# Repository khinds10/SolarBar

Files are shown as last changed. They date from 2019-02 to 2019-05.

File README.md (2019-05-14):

# Sunrise Alarm Clock
Schedule your own personal sunrise, improves morning wakefulness

Latest random invention, schedule your own sunrise!

During the day, the blue light in sunlight boosts our attention, memory, energy levels, reaction times, and overall mood.
Blue light suppresses the release of melatonin, for morning use only :)

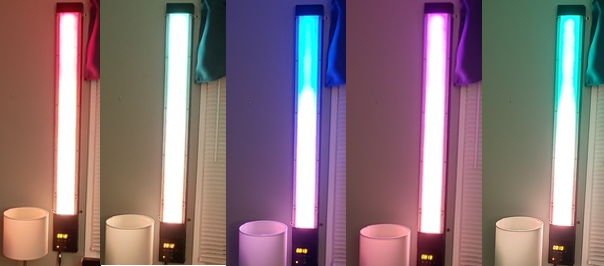
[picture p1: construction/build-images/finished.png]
Finished


Sunrise Alarm Clock (https://www.youtube.com/watch?v=JoXHWPglelI)

#### Flashing RaspberriPi Hard Disk / Install Required Software (Using Ubuntu Linux)

Download "RASPBIAN JESSIE LITE"
https://www.raspberrypi.org/downloads/raspbian/

**Create your new hard disk for DashboardPI**
>Insert the microSD to your computer via USB adapter and create the disk image using the `dd` command
>
> Locate your inserted microSD card via the `df -h` command, unmount it and create the disk image with the disk copy `dd` command
>
> $ `df -h`
> */dev/sdb1       7.4G   32K  7.4G   1% /media/XXX/1234-5678*
> a
> $ `umount /dev/sdb1`
>
> **Caution: be sure the command is completely accurate, you can damage other disks with this command**
>
> *if=location of RASPBIAN JESSIE LITE image file*
> *of=location of your microSD card*
>
> $ `sudo dd bs=4M if=/path/to/raspbian-jessie-lite.img of=/dev/sdb`
> *(note: in this case, it's /dev/sdb, /dev/sdb1 was an existing factory partition on the microSD)*

**Setting up your RaspberriPi**

*Insert your new microSD card to the raspberrypi and power it on with a monitor connected to the HDMI port*

Login
> user: **pi**
> pass: **raspberry**

Change your account password for security
>`sudo passwd pi`

Enable RaspberriPi Advanced Options
>`sudo raspi-config`

Choose:
`1 Expand File System`

`9 Advanced Options`
>`A2 Hostname`
>*change it to "SOLARLAMP"*
>
>`A4 SSH`
>*Enable SSH Server*
>
>`A7 I2C`
>*Enable i2c interface*
>
>`P4 SPI`
>*Enable/Disable automatic loading of SPI kernel module*
>

**Enable the English/US Keyboard**

>`sudo nano /etc/default/keyboard`

> Change the following line:
>`XKBLAYOUT="us"`

**Reboot PI for Keyboard layout changes / file system resizing to take effect**
>$ `sudo shutdown -r now`

**Auto-Connect to your WiFi**

>`sudo nano /etc/wpa_supplicant/wpa_supplicant.conf`

Add the following lines to have your raspberrypi automatically connect to your home WiFi
*(if your wireless network is named "linksys" for example, in the following example)*

	network={
	   ssid="linksys"
	   psk="WIRELESS PASSWORD HERE"
	}

**Reboot PI to connect to WiFi network**

>$ `sudo shutdown -r now`
>
>Now that your PI is finally on the local network, you can login remotely to it via SSH.
>But first you need to get the IP address it currently has.
>
>$ `ifconfig`
>*Look for "inet addr: 192.168.XXX.XXX" in the following command's output for your PI's IP Address*

**Go to another machine and login to your raspberrypi via ssh**

> $ `ssh pi@192.168.XXX.XXX`

**Start Installing required packages**

>$ `sudo apt-get update`
>
>$ `sudo apt-get upgrade`
>
>$ `sudo apt-get install memcached vim git python-gpiozero python-smbus i2c-tools python-imaging python-smbus build-essential python-dev rpi.gpio python3 python3-pip python-memcache python3-spidev python-spidev`

**Update local timezone settings

>$ `sudo dpkg-reconfigure tzdata`

`select your timezone using the interface`

**Setup the simple directory `l` command [optional]**

>`vi ~/.bashrc`
>
>*add the following line:*
>
>`alias l='ls -lh'`
>
>`source ~/.bashrc`

**Fix VIM default syntax highlighting [optional]**

>`sudo vi  /etc/vim/vimrc`
>
>uncomment the following line:
>
>_syntax on_

**Install i2c Python Drivers**

Install the NeoPixel Driver as follows 

>`sudo apt-get install build-essential python-dev git scons swig`
>
>`sudo pip3 install --upgrade setuptools`
>
>`sudo pip3 install rpi_ws281x`
>
>`cd rpi_ws281x`
>
>`scons`
>
>`cd python`
>
>`sudo python setup.py install`
>
>`cd examples/`
>
>`sudo python strandtest.py`

# Supplies Needed

**5V Power Supply**

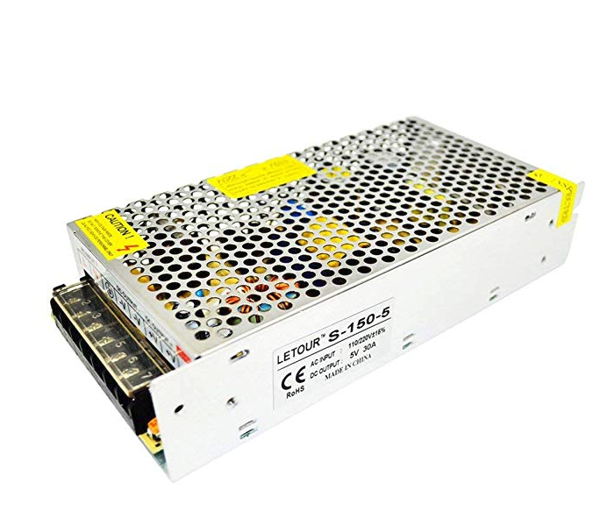
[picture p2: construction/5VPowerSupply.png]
5V Power Supply


**I2C 7 SEGMENT**

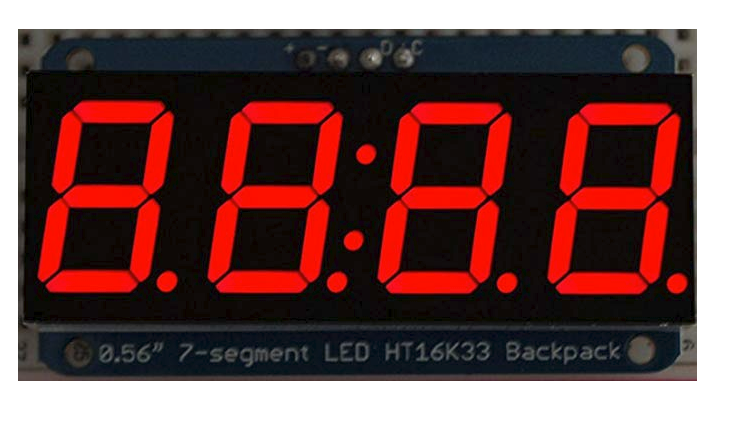
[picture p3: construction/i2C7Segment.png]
I2C 7 SEGMENT


**Microchip MCP3008**

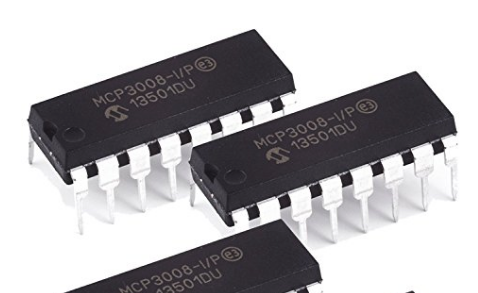
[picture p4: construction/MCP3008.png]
Microchip MCP3008


**Momentary Tactile Tact Push Button Switch [x5]**

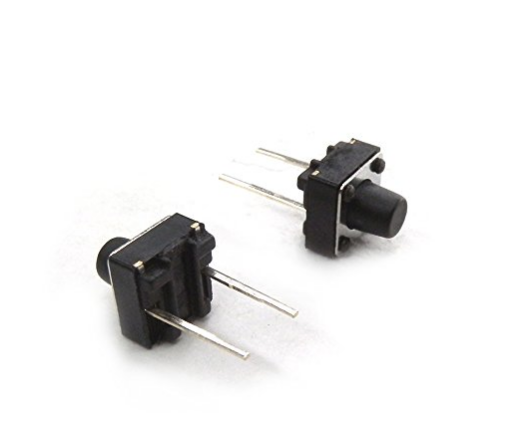
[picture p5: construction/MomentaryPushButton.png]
Momentary Tactile Tact Push Button Switch


**PI ZERO W**

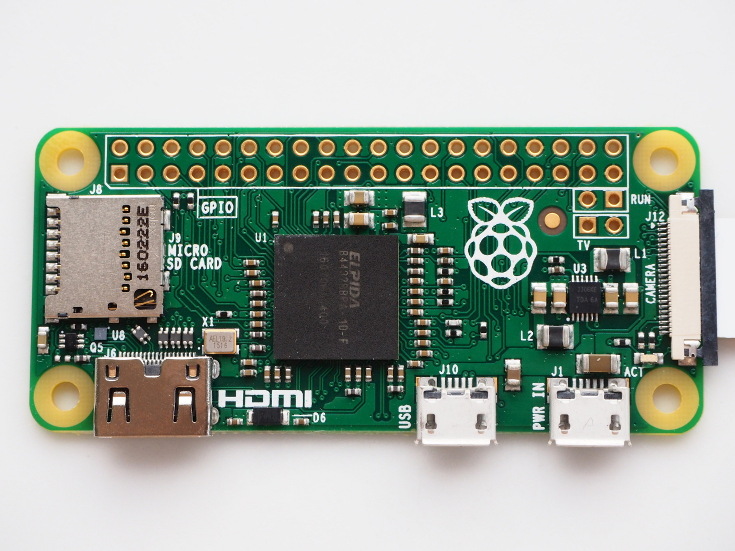
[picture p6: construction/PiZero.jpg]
PI ZERO W


**Logarithmic Slide Potentiometer**

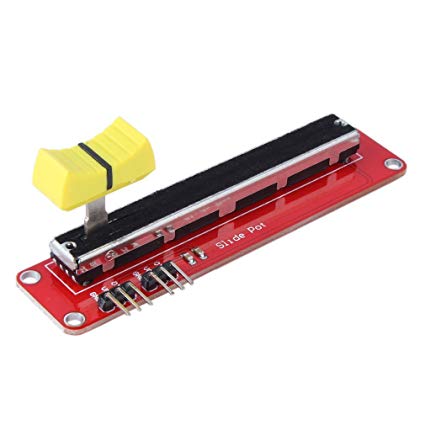
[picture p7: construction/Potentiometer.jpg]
Logarithmic Slide Potentiometer


**WS2812B Individually Addressable RGB LED Strip [x4]**

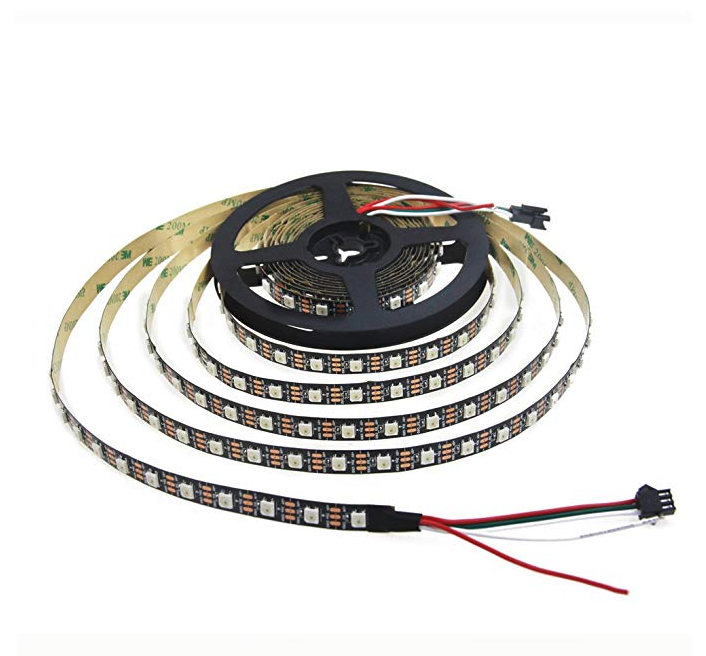
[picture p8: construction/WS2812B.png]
WS2812B Individually Addressable RGB LED Strip


**Thin Plexi Glass Sheet**

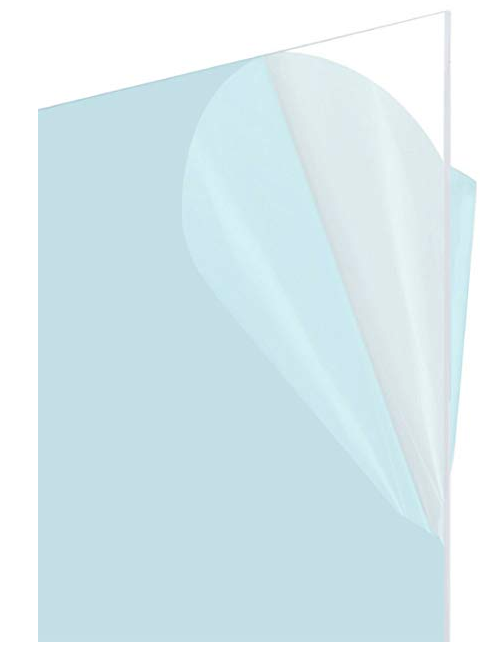
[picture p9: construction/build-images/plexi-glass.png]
Plexi Glass


**Frosted Spray Paint**

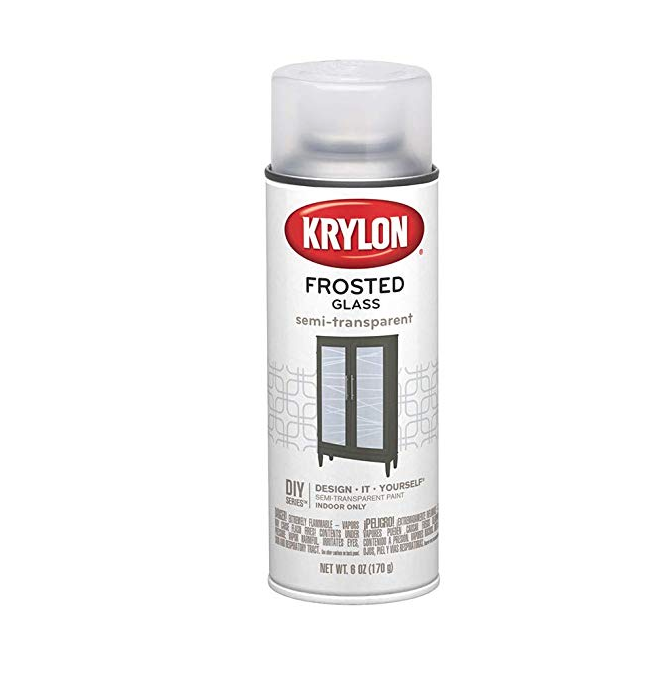
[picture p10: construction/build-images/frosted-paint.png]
Frosted Spray Paint


### 3D Print the Controller Panel

Using the .x3g files included in the "3D Print/" folder print the main control panel cover, which will house the slider, buttons, LED and 7 Segment display

### Building the Lamp

**Build Wood Frame**

I've built a wooden frame for the LED strips to be enclosed in and painted it black.

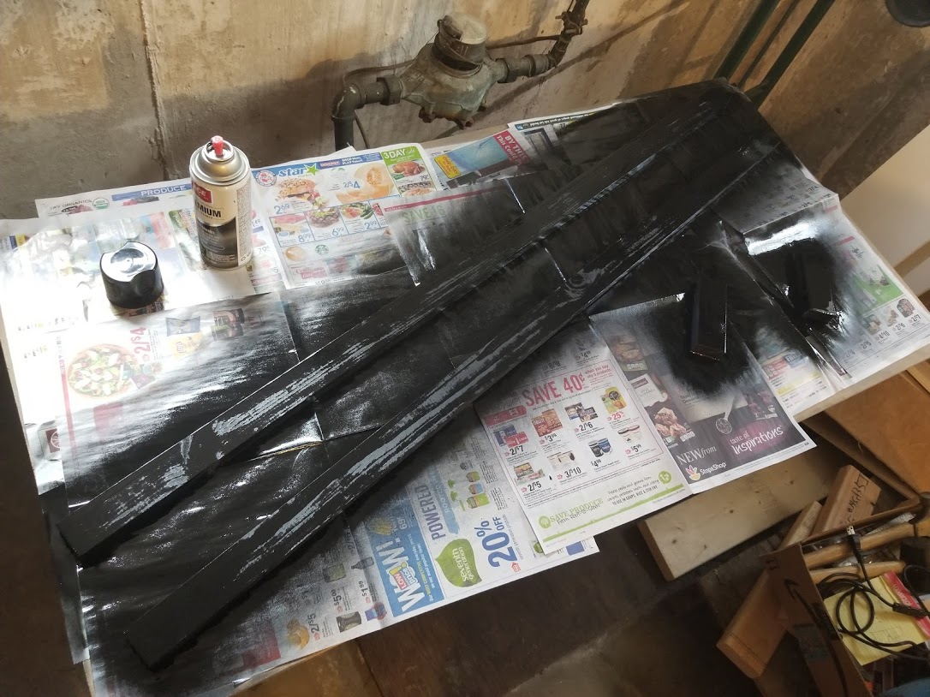
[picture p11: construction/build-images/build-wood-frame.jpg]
Build Wood Frame


**Paint Plexi Glass**

With some frosted spray paint, paint the glass so that it defuses the light from the strips.

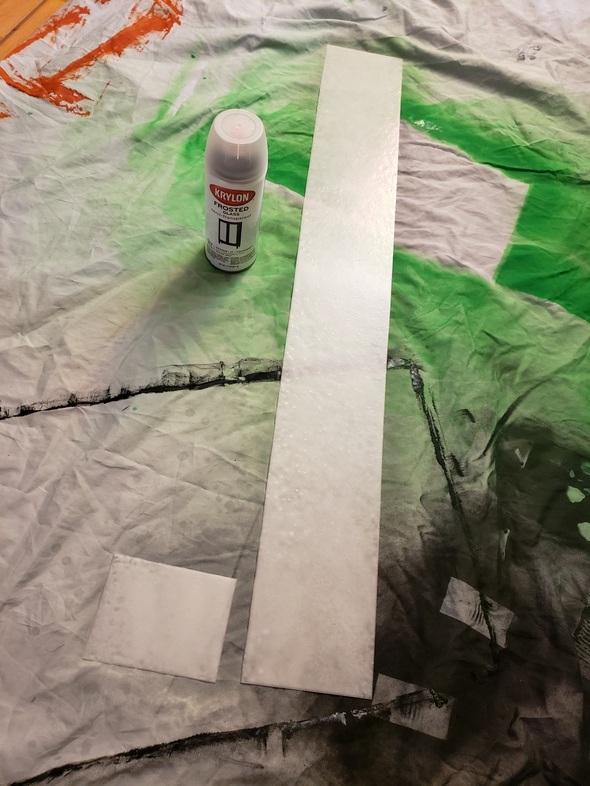
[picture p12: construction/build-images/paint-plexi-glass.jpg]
Paint Plexi Glass


**Mount Strips**

Using simple tape and the stickiness of the backside of the LED strips, mount the 4 strips to the wooden base

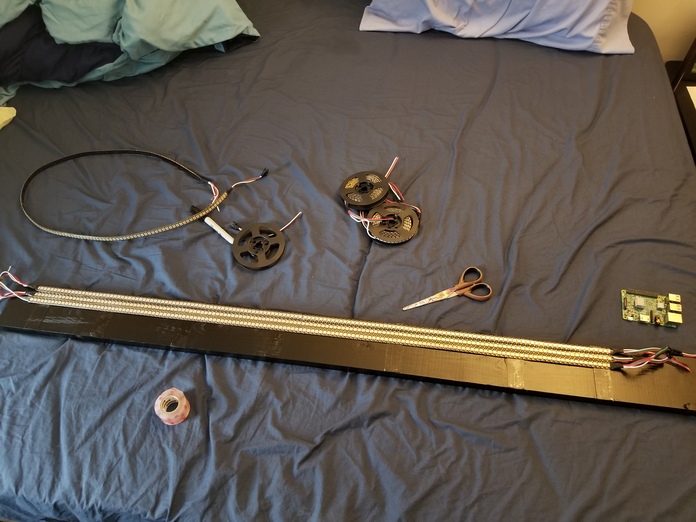
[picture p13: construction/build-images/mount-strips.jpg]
Mount Strips


**Mount Buttons**

Mount the buttons and the yellow LED, I've used hot glue to hold the buttons and LED in place.

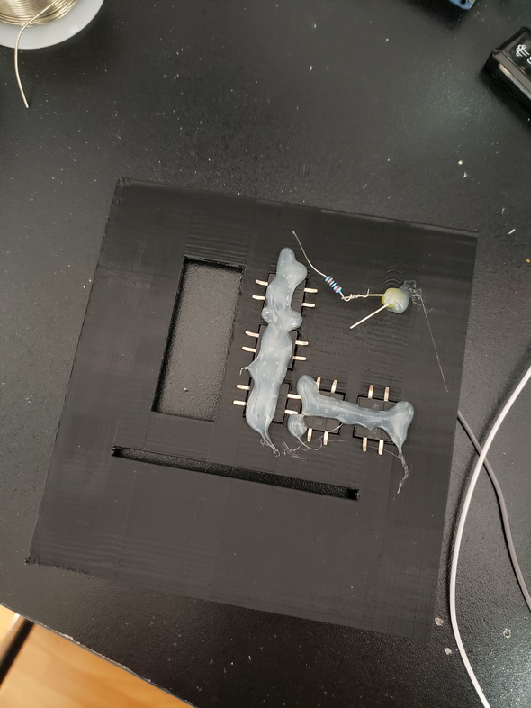
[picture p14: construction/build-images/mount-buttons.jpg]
Mount Buttons


**Mount Buttons on Panel**

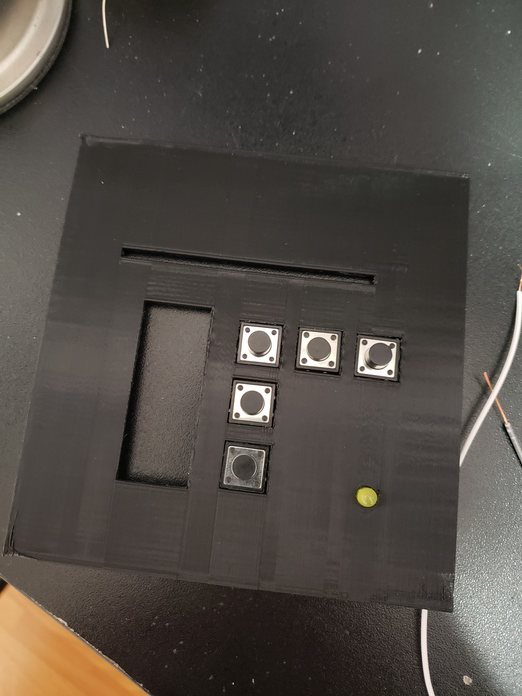
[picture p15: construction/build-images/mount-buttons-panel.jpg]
Mount Buttons on Panel


**Mount Chip on the Slider**

Following the provided schematic, solder the chip wiring in place and connect to the logarithmic slider, glue the chip with solder connections to the back of the slider.

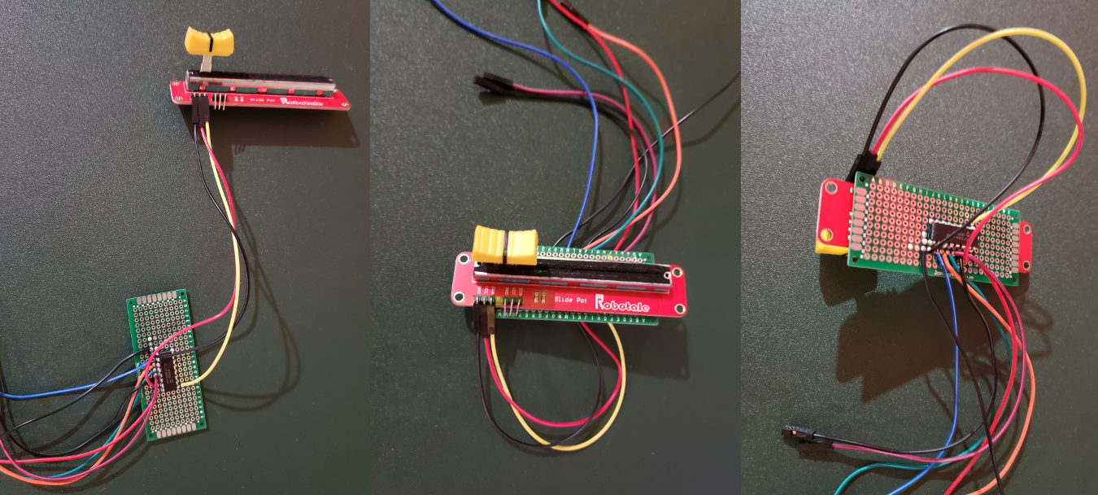
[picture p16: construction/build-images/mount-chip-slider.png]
Mount Chip on the slider


### Wiring the Components

Use the following Schematic to connect all the components to have the lamp work properly.

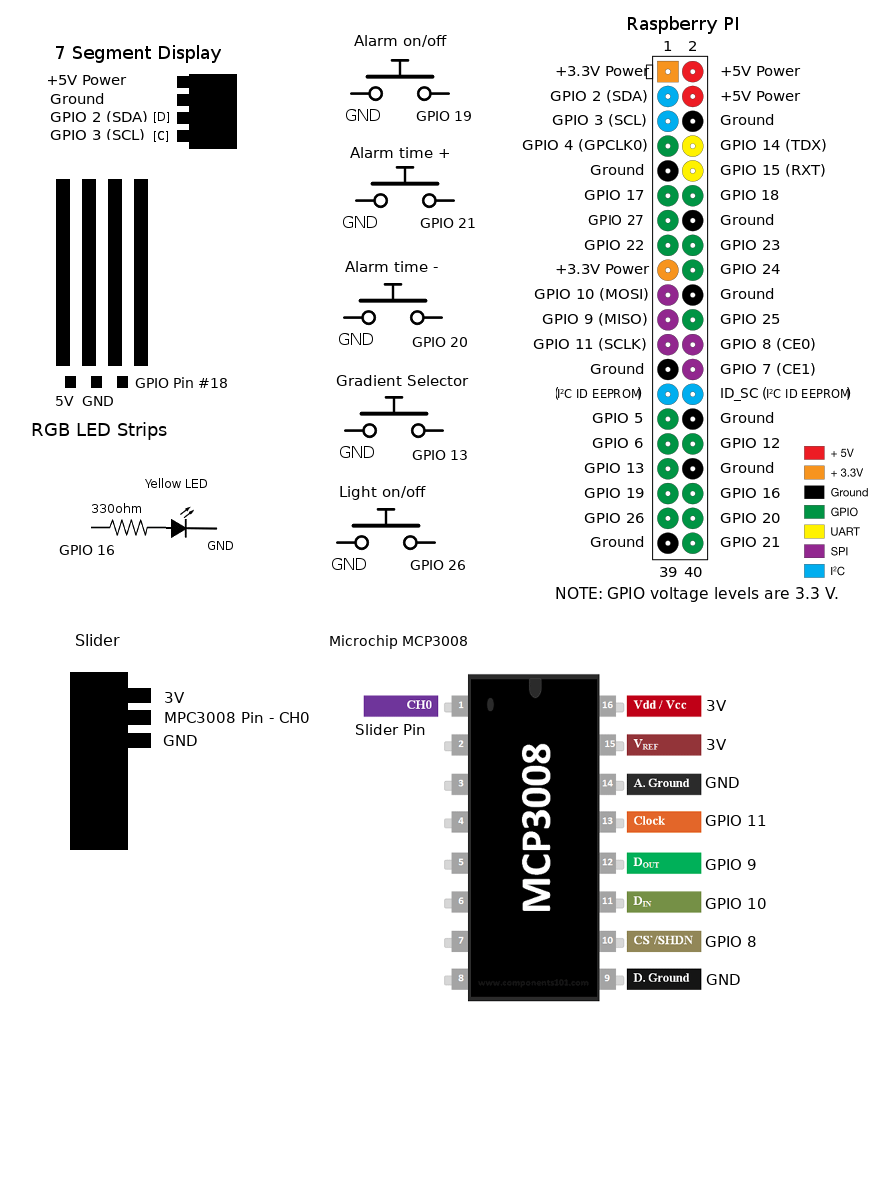
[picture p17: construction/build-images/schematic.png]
Schematic


**Wire Panel**

Connect all wiring to the components glued on the panel to connect to the raspberrypi.

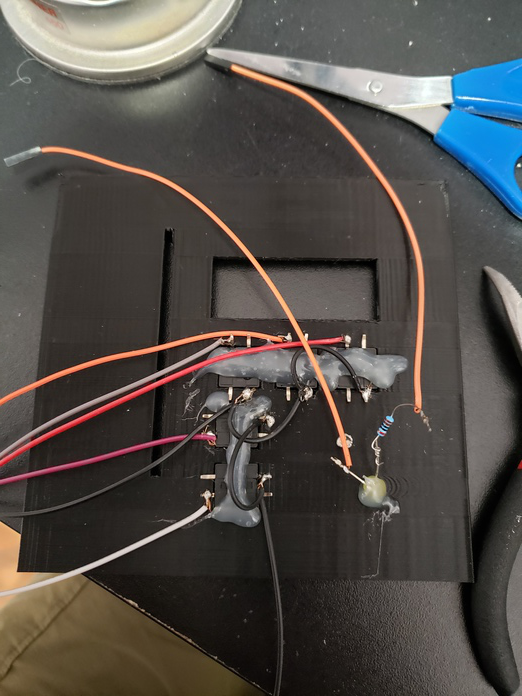
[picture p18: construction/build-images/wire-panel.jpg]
Wire Panel


**Wire Pi**

Finally attach the PiZero to the back board of the LED wooden case with tape or glue and then connect the wiring according the provided schematic.

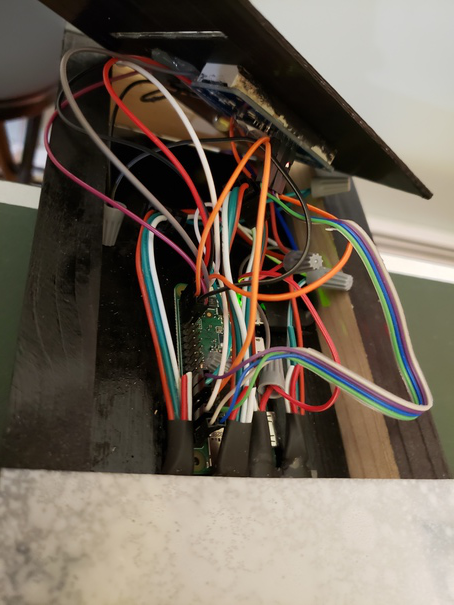
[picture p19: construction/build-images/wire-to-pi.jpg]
Wire Pi


**Mount Panel**

Fasten the control panel on the bottom of the LED case.

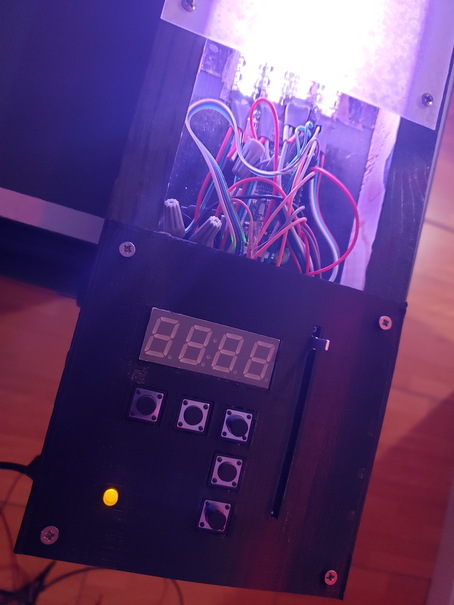
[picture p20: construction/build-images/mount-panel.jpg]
Mount Panel


**Apply Plexi Glass**

Attach cut and painted plexi glass to the LED case with screws

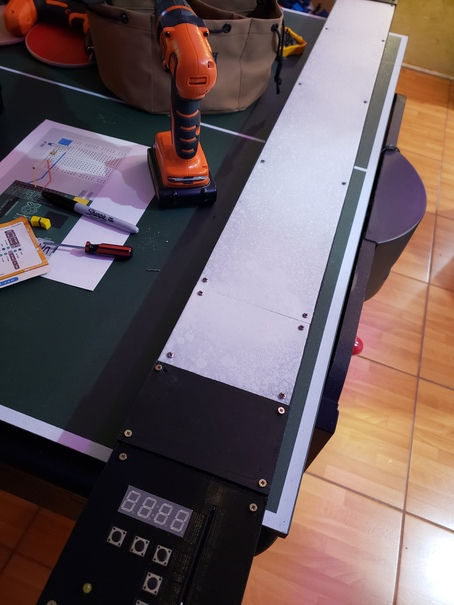
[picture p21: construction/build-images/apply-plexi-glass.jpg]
Apply Plexi Glass


**Mount on the Wall**

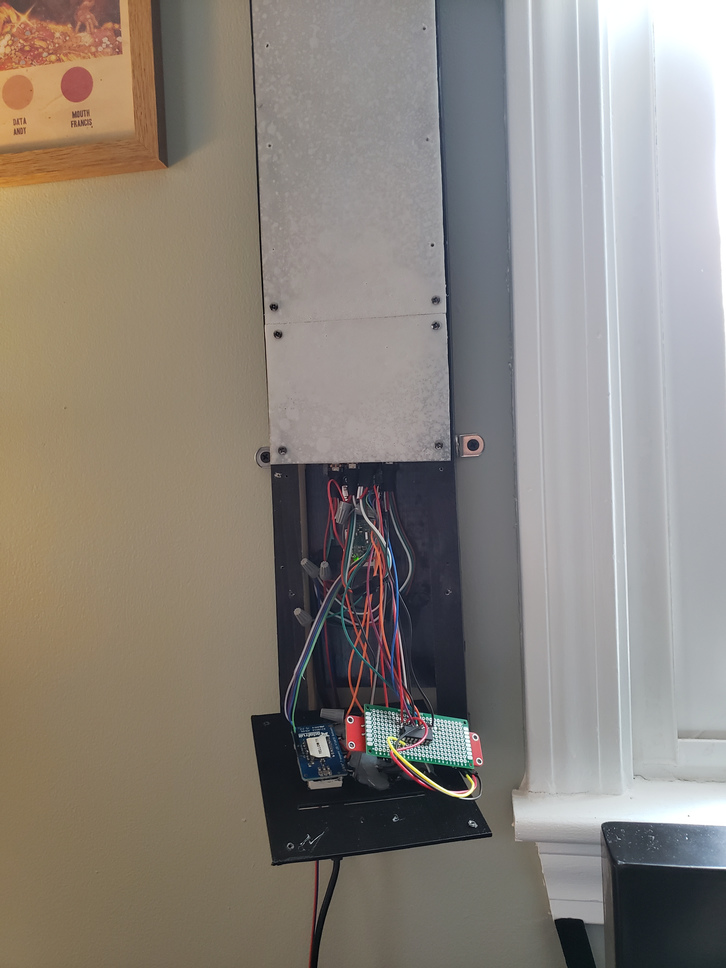
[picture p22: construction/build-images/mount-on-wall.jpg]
Mount on the Wall


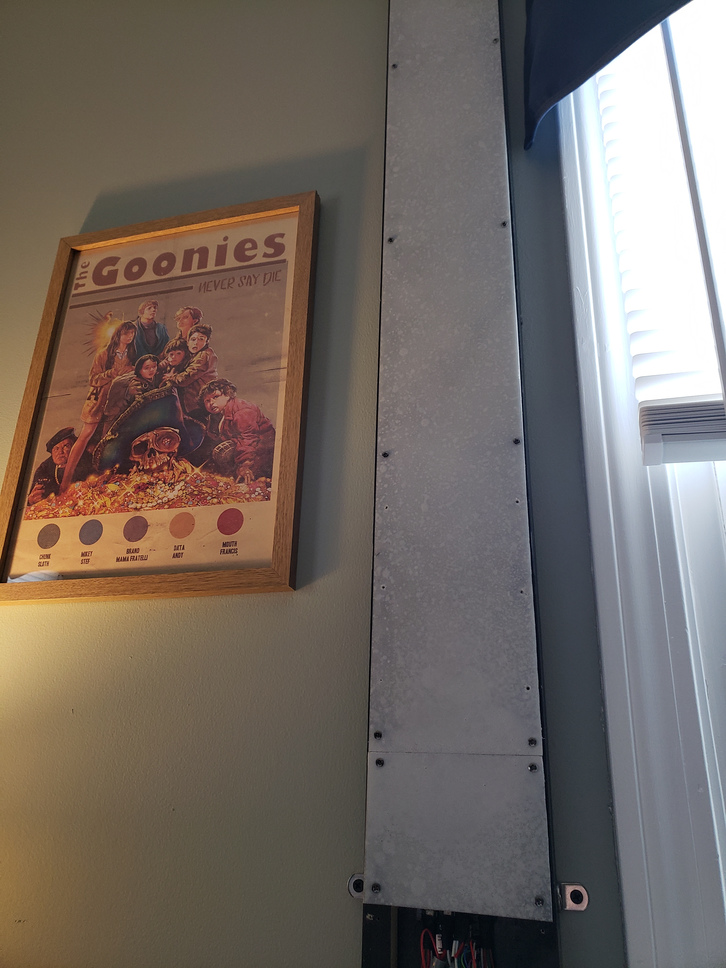
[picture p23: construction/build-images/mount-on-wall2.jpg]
Mount on the Wall


### Set pi user crontab 

Enter the following line for a minute by minute crontab

`$ crontab -e`

`0 3 * * * python /home/pi/SolarBar/Alarm.py > /dev/null 2>&1`

`@reboot python /home/pi/SolarBar/Buttons.py > /dev/null 2>&1`

`@reboot python /home/pi/SolarBar/ControlPanel.py > /dev/null 2>&1`

`@reboot python /home/pi/SolarBar/Slider.py > /dev/null 2>&1`

### Set root user crontab (this library requires root access)

Set "on reboot" to run the candle python script forever

`$ sudo su`

`$ crontab -e`

`@reboot python /home/pi/SolarBar/LEDs.py > /dev/null 2>&1`

# Finished!

Finished

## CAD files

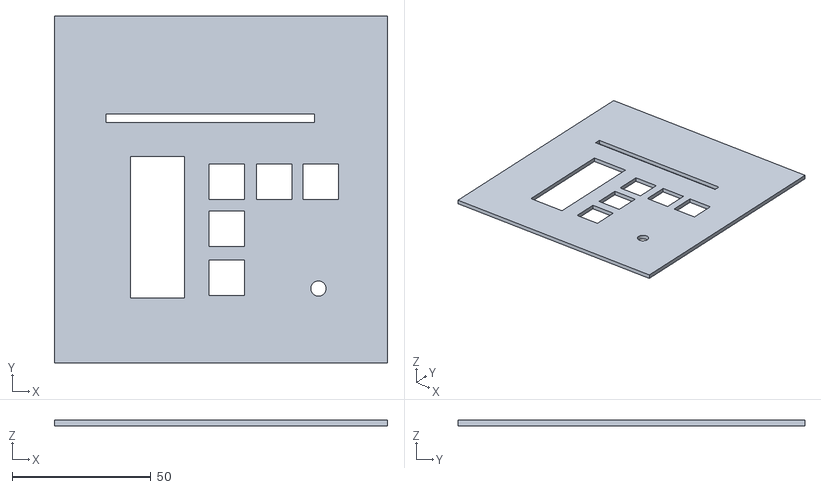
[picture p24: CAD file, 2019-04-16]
3D Print/ControlPanel-final-cut.stl
120.0 x 125.0 x 2.00

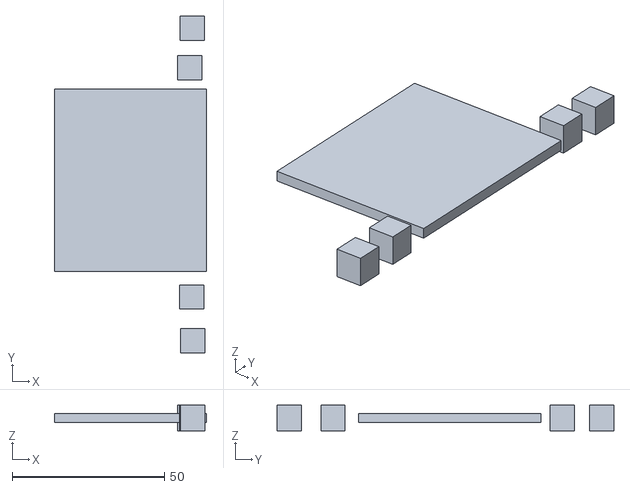
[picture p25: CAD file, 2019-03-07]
3D Print/ButtonMount.stl
50.0 x 110.7 x 8.50

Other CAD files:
3D Print/ControlPanel.stl
3D Print/ControlPanel-Cut-Large-Buttons.blend
3D Print/ControlPanel-Cut.blend
3D Print/ControlPanel-button-mount.blend
3D Print/ControlPanel-final-cut.blend
3D Print/ControlPanel-pre-cut.blend
3D Print/ControlPanel.blend

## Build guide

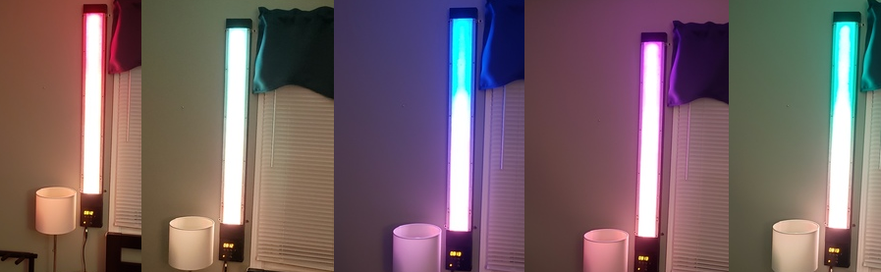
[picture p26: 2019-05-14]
construction/build-images/gradients.png

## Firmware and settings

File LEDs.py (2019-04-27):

#! /usr/bin/python
# Solar Bar, color strip controller
# Kevin Hinds http://www.kevinhinds.com
# License: GPL 2.0
import time, commands, subprocess, re, json, sys, os, memcache, numpy
from PIL import Image
from neopixel import *
import includes.data as data

# LED strip configuration:import settings as settings
LED_COUNT       = 576     # Number of LED pixels.
LED_STRIP_COUNT = 4       # How many strips are there total for the number of pixels
LED_PIN         = 18      # GPIO pin connected to the pixels (18 uses PWM!).
LED_FREQ_HZ     = 800000  # LED signal frequency in hertz (usually 800khz)
LED_DMA         = 10      # DMA channel to use for generating signal (try 10)
LED_BRIGHTNESS  = 255     # Set to 0 for darkest and 255 for brightest
LED_INVERT      = False   # True to invert the signal (when using NPN transistor level shift)
LED_CHANNEL     = 0       # set to '1' for GPIOs 13, 19, 41, 45 or 53
LED_TOTAL_STRIPS = LED_COUNT/LED_STRIP_COUNT

##################################################
######## YOU HAVE TO RUN AS ROOT!
##################################################

# setup the strip
strip = Adafruit_NeoPixel(LED_COUNT, LED_PIN, LED_FREQ_HZ, LED_DMA, LED_INVERT, LED_BRIGHTNESS, LED_CHANNEL, ws.WS2811_STRIP_GRB)
strip.begin()

def reset():
    """turn all lights off RGB = 000"""
    global isIllumniated
    print "reset()"
    for i in range(0, LED_COUNT):
        strip.setPixelColor(i, Color(0, 0, 0))
    isIllumniated = False
    strip.show()

def illuminate():
    """turn on the strip to the current gradient set"""
    global isIllumniated, currentImage
    print "illuminate()"
    currentPixel = 0
    evenNumberedStrip = False
    for currentStrip in range(0, LED_COUNT, (LED_TOTAL_STRIPS)):
        currentPixel = 0
        if evenNumberedStrip:
            for ledLight in range(currentStrip, currentStrip + (LED_TOTAL_STRIPS), 1):
                r,g,b,a = currentImage[currentPixel]
                strip.setPixelColor(ledLight, Color(r,g,b))
                currentPixel = currentPixel + 1
        else:
            for ledLight in range(currentStrip + (LED_TOTAL_STRIPS), currentStrip, -1):
                r,g,b,a = currentImage[currentPixel]
                strip.setPixelColor(ledLight, Color(r,g,b))
                currentPixel = currentPixel + 1

        # the LED strips are upside down, right side up sequentially on the device, so we must iterate through back and forth the LEDs
        evenNumberedStrip = not evenNumberedStrip       
    isIllumniated = True
    strip.show()

def saveDebugImage():
    """save debug image to show what the panel will display"""
    global currentImage
    newImage = Image.new("RGB", (1,len(currentImage)))
    newImage.putdata(currentImage)
    newImage.save('/home/pi/SolarBar/currentPanelColors.png')

def shiftGradient():
    """move the gradient"""
    print "shiftGradient() = " + str(currentSunrisePosition)
    global currentSunrisePosition, currentImage
    if currentSunrisePosition > (imgHeight - 1):
        currentSunrisePosition = imgHeight - 1        
    currentImage = imagePixels[currentSunrisePosition:currentSunrisePosition + (LED_TOTAL_STRIPS)]
    saveDebugImage()
    
def getGradient():
    """get the gradient chosen into memory"""
    global currentImage, imgWidth, imgHeight, imagePixels
    print "getGradient() = " + str(gradientSet)
    im = Image.open('/home/pi/SolarBar/gradients/' + str(gradientSet) + '.png')
    imagePixels = list(im.getdata())
    imgWidth, imgHeight = im.size

    # the sun color is always at the bottom and can 'consume' more and more of the current gradient
    currentSunrisePosition = 0
    sunColor = imagePixels[-1]

    # cut one line out of the image and pad it with the "full sun color" at the bottom
    completeGradient = []
    for i in range(0, (imgWidth * imgHeight) * 2, imgWidth):
        if i < (imgWidth * imgHeight):
            completeGradient.append(imagePixels[i])
        else:
            completeGradient.append(sunColor)
    imagePixels = completeGradient

    # get current gradient as is to be manipulated, original image 
    #   that the completeGradient can slowly take over as the "sun rises" or control panel adjusted
    currentImage = imagePixels[0:(LED_TOTAL_STRIPS)]
    saveDebugImage()

def getCurrentPanelSettings():
    """get the currently set values for what the light panel is supposed to reflect"""
    global gradientSet, lightOn, currentPosition
    gradientSet = data.getJSONFromDataFile('/home/pi/SolarBar/data/gradient.data')
    lightOn = data.getJSONFromDataFile('/home/pi/SolarBar/data/lightOn.data')
    try:
        currentPosition = int(data.getJSONFromDataFile('/home/pi/SolarBar/data/position.data'))
        currentPosition = int(currentPosition * 4.5)
    except:
        currentPosition = 0
    print "getCurrentPanelSettings() = gradientSet: " + str(gradientSet) + " / lightOn: " + str(lightOn) + " / currentPosition: " + str(currentPosition)

# load current settings for the panel
gradientSet, lightOn, currentPosition, isIllumniated = ["1", "0", "0", False]
prevGradient, prevPosition= ["1", "0"]
imgWidth, imgHeight = [0,0]
imagePixels = None
getCurrentPanelSettings()
reset()
getGradient()

# begin the panel
while True:
    try:
        # light on/off if changed
        if lightOn == "1" and not isIllumniated:
            illuminate()
        if lightOn == "0" and isIllumniated:
            reset()

        # update gradient if new one is set
        if gradientSet != prevGradient:
            getGradient()
            if isIllumniated:
                illuminate()
            prevGradient = gradientSet

        # update 
        if currentPosition != prevPosition:
            currentSunrisePosition = currentPosition
            shiftGradient()
            if isIllumniated:
                illuminate()
            prevPosition = currentPosition

        # go around again
        getCurrentPanelSettings()
        time.sleep(0.1)
    except (Exception):
        time.sleep(0.1)

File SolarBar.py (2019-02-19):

#! /usr/bin/python
# Solar Bar, main script
# Kevin Hinds http://www.kevinhinds.com
# License: GPL 2.0
import time, commands, subprocess, re, json, sys, os, memcache
from datetime import datetime
mc = memcache.Client(['127.0.0.1:11211'], debug=0)
from Adafruit_LED_Backpack import SevenSegment
import RPi.GPIO as GPIO

# setup alarm on / off LED
GPIO.setmode(GPIO.BCM)
GPIO.setwarnings(False)
GPIO.setup(16,GPIO.OUT)

# 7 Segment Clock on i2c on address 0x70
segment = SevenSegment.SevenSegment(address=0x71)

# initialize the display, must be called once before using the display.
segment.begin()
segment.set_brightness(3)
segment.set_colon(True)

# application defaults
sunriseTimeHour = 7
sunriseTimeMin = 0
alarmOn = 'False'
lightOn = 'False'

def getJSONFromDataFile(fileName):
    """get JSON contents from file in question"""
    try:
        with open(fileName) as locationFile:    
            return json.load(locationFile)
    except (Exception):
        return ""

def toggleAlarmOnLight(alarmOn):
    """toggle alarm on light"""
    print alarmOn
    if alarmOn == 'True':
        GPIO.output(16,GPIO.HIGH)
    else: 
        GPIO.output(16,GPIO.LOW)

def saveAlarmTime(hour, minute):
    """save the hour and minutes the sunrise alarm is set to"""
    f = file('alarm.data', "w")
    alarmTime = [hour, minute]
    f.write(str(json.dumps(alarmTime)))

def saveAlarmOn(alarmOn):
    """save if the alarm is turned on or off"""
    f = file('alarmSet.data', "w")
    f.write(str(json.dumps(alarmOn)))
    
def saveLightOn(lightOn):
    """save if the light is turned on or off"""
    f = file('lightOn.data', "w")
    f.write(str(json.dumps(lightOn)))
    
def setDisplay(hour, minute):
    """set 7 segment display with hour and minute"""
    if (hour > 12):
        hour = hour - 12  
    segment.clear()
    segment.set_digit(0, int(hour / 10))
    segment.set_digit(1, hour % 10)
    segment.set_digit(2, int(minute / 10))
    segment.set_digit(3, minute % 10)
    segment.write_display()

# run script, check for button presses
alarm = getJSONFromDataFile('alarm.data')
alarmOn = getJSONFromDataFile('alarmSet.data')
toggleAlarmOnLight(alarmOn)
setDisplay(alarm[0], alarm[1])
while True:
    buttonPress = mc.get("BUTTON")
    if buttonPress is not "":
        print buttonPress

    # increase time by 15 min increments, increasing hour up to 23 hundred
    if buttonPress == "UP":
        sunriseTimeMin = sunriseTimeMin + 15
        if sunriseTimeMin > 45:
            sunriseTimeMin = 0
            sunriseTimeHour = sunriseTimeHour + 1
        if sunriseTimeHour > 23:
            sunriseTimeHour = 0

        # show new alarm time on 7 segment
        setDisplay(sunriseTimeHour, sunriseTimeMin)
        saveAlarmTime(sunriseTimeHour, sunriseTimeMin)
        time.sleep(1)

    # decrease time by 15 min increments, resetting hour back to 23 hundred
    if buttonPress == "DOWN":
        sunriseTimeMin = sunriseTimeMin - 15
        if sunriseTimeMin < 0:
            sunriseTimeMin = 45
            sunriseTimeHour = sunriseTimeHour - 1
        if sunriseTimeHour < 0:
            sunriseTimeHour = 23

        # show new alarm time on 7 segment
        setDisplay(sunriseTimeHour, sunriseTimeMin)
        saveAlarmTime(sunriseTimeHour, sunriseTimeMin)
        time.sleep(1)

    # turn on / off the alarm LED, save the settings to file
    elif buttonPress == "ALARM":
        if alarmOn == 'True':
            alarmOn = 'False'
        elif alarmOn == 'False':
            alarmOn = 'True'
        toggleAlarmOnLight(alarmOn)
        saveAlarmOn(alarmOn)

    # turn on and off the light
    elif buttonPress == "LIGHT":
        if lightOn == 'True':
            lightOn = 'False'
        elif lightOn == 'False':
            lightOn = 'True'
        saveLightOn(lightOn)

    # wait and go around again
    mc.set("BUTTON", "")
    time.sleep(0.1)

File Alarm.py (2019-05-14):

#! /usr/bin/python
# Solar Bar, alarm manager
# Kevin Hinds http://www.kevinhinds.com
# License: GPL 2.0
import time, commands, subprocess, re, json, sys, os, memcache, json, datetime
import includes.data as data
mc = memcache.Client(['127.0.0.1:11211'], debug=0)

#-------------------------------------------------------------------------------------------------------------
# cronjob runs this script at 4am sleep till alarm set time, then start the sunrise gradient illumination
#-------------------------------------------------------------------------------------------------------------

def percentage(part, whole):
  return 100 * float(part)/float(whole)

# get the upcoming timestamp for when the alarm is set for today
isAlarmSet = data.getJSONFromDataFile("/home/pi/SolarBar/data/alarmSet.data")
alarmTime = data.getJSONFromDataFile("/home/pi/SolarBar/data/alarm.data")
timeNow = datetime.datetime.now()
timeStruct = (timeNow.year, timeNow.month, timeNow.day, alarmTime[0], alarmTime[1], timeNow.second, datetime.datetime.now().timetuple().tm_wday, datetime.datetime.now().timetuple().tm_yday, datetime.datetime.now().timetuple().tm_isdst)
alarmTimestamp = time.mktime(timeStruct)

# how long the alarm will run for
seconds = 60*30

# if the alarm is set, then begin the sunrise at the designated time
if isAlarmSet == "True":
    timeTillAlarm = alarmTimestamp - time.time()
    if (timeTillAlarm > 0):
        print "Sleeping till Alarm is set (zzz): " + str(timeTillAlarm) + " seconds"
        time.sleep(timeTillAlarm)
        
        # alarm is ringing, begin the gradient
        print "Alarm is ringing"
        mc.set("INUSE", "INUSE")
        second = 0
        percent = 0
        data.saveLightOn('1')
        data.saveSliderPosition('0')
        while second < seconds:
            second = second + 1
            percent = int(percentage(second, seconds))
            print "Sun is " + str(percent) + "% risen"
            data.saveSliderPosition(str(percent))
            time.sleep(1)

        # wait another cycle of the seconds passing then turn off the light
        time.sleep(seconds)
        data.saveLightOn('0')
        mc.set("INUSE", "")

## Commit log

2019-02-11 Basic Scripts for controlling devices
2019-02-19 basic buttons and control panel working
2019-02-22 start getting the LEDs to work
2019-03-07 3D print files, Alarm script, NeoPixel driver ZIP file, LED sunrise script
    [ButtonMount.stl, ControlPanel-Cut.blend, ControlPanel-button-mount.blend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]
2019-03-07 got it working with LED strips animating the sunrise!
2019-03-19 fix brightness git conflict
    [LEDs.py]
2019-03-25 working values from data files to control control panel and light panel correctly so far
    [Alarm.py, Buttons.py, ControlPanel.py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]
2019-03-26 some bugs fixed for the illumination, testing now with 4 strips for maximum effect
    [ControlPanel.py, LEDs.py, Slider.py]
2019-04-01 fix paths to run as cronjobs
    [Alarm.py, ControlPanel.py, LEDs.py]
2019-04-16 updates for having the slider finally work
    [ControlPanel-Cut-Large-Buttons.blend, ControlPanel-Cut.blend, ControlPanel-final-cut.blend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]
2019-04-20 added new gradient functions and the display now always shows something and reacts to the buttons
2019-04-20 changed slider pin for final construction
2019-04-21 final updates for working light, need to upgrade to the MCP3008 chip for the slider to really work correctly however still
    [Buttons.py, ControlPanel.py, LEDs.py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]
2019-04-27 got panel working on wall, only illuminate on change gradient or position change if already lit, change display to correctly show 100%
    [ControlPanel.py, LEDs.py]
2019-05-03 added wiring diagram
